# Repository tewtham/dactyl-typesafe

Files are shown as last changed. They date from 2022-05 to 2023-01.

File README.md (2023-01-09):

# Dactyl TypeSafe
A vertical split keyboard inspired by the [SafeType](https://www.amazon.com/SafeType-Keyboard-Black-Color-V902/dp/B0049PFYWQ) and [dactyl](https://github.com/adereth/dactyl-keyboard).
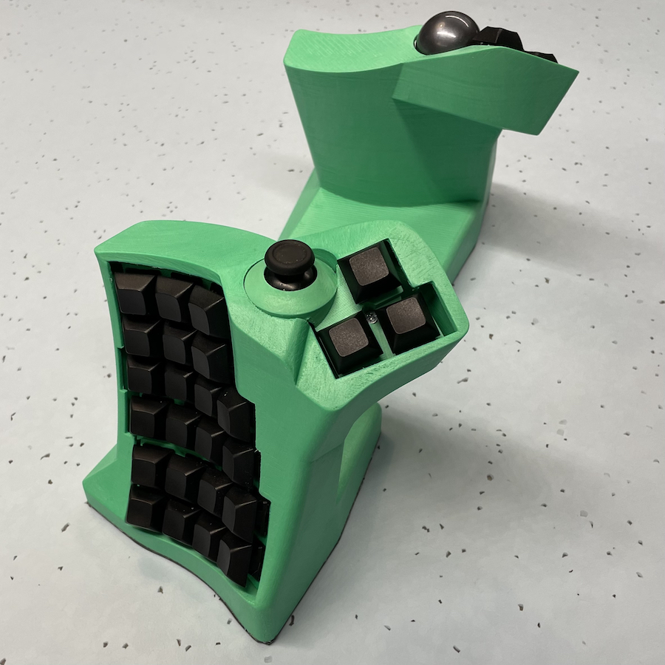
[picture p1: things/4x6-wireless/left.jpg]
left

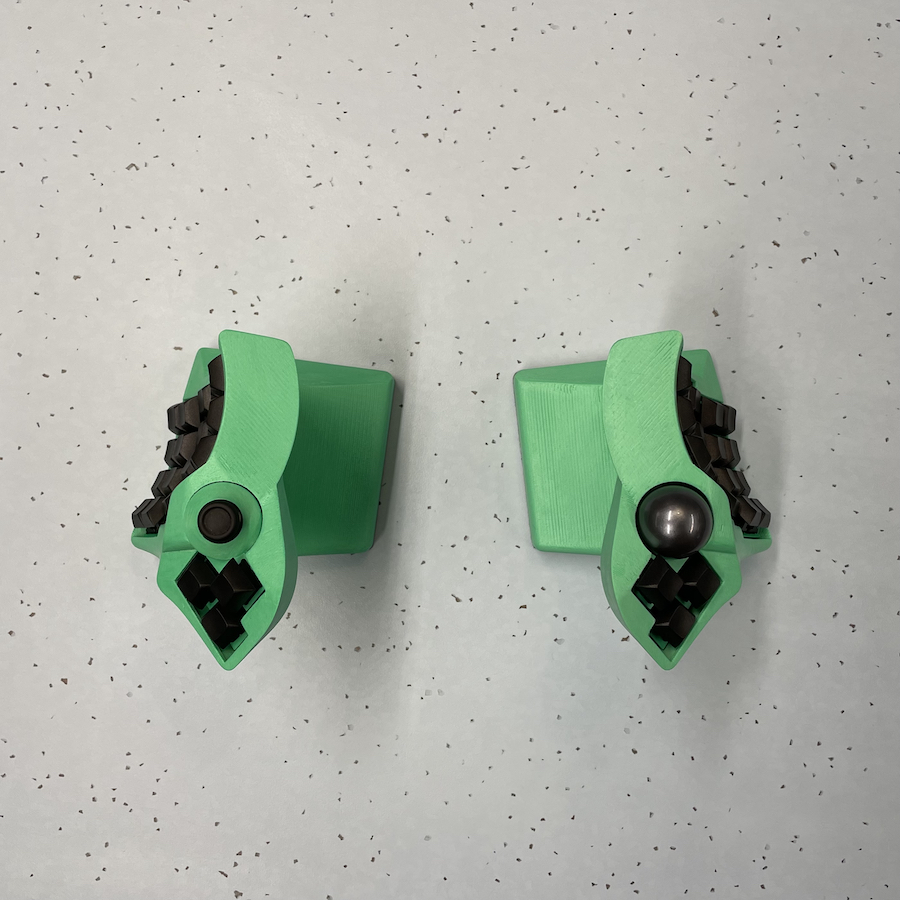
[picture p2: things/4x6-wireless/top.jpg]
both

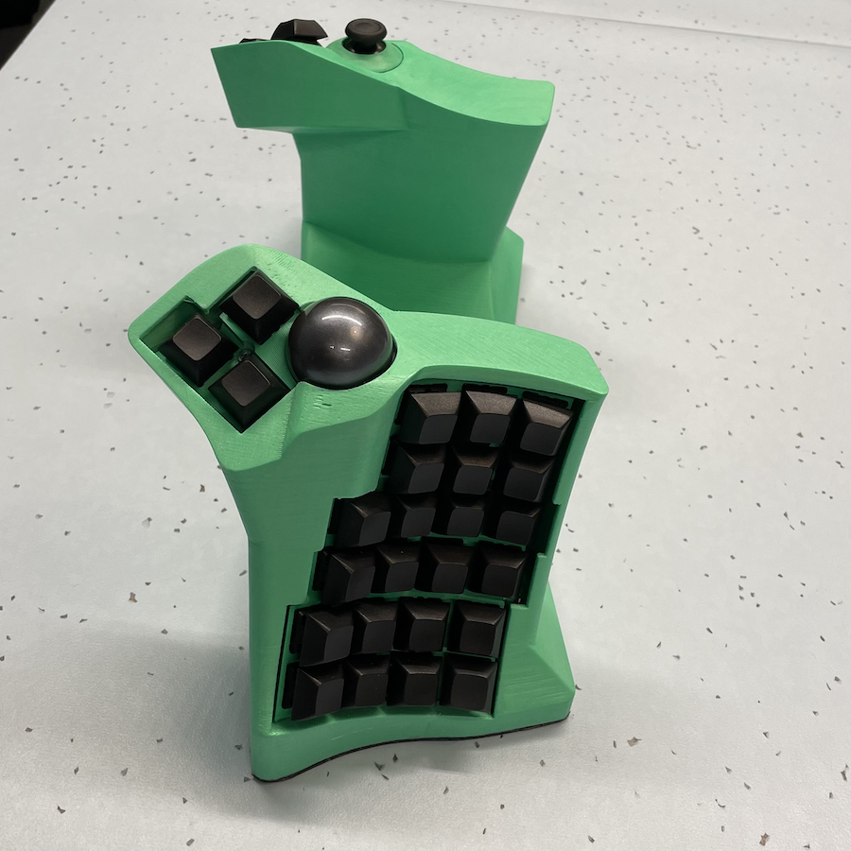
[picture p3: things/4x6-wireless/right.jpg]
right


## Parts list
1. [nylon 8mm ball transfer units](https://www.aliexpress.com/item/32839736943.html) * 3 for the trackball.
1. [non-slip mat](https://www.amazon.com/ROOS-Self-Stick-Anti-Skid-Furniture-Protectors/dp/B01K7JFXAA)
1. 34mm ball
    - Any 34mm ball will probably work, but I think it's best to use [a replacement trackball](https://www.aliexpress.com/item/4000351102541.html). You will get better response and precision.
1. [pmw3360 laser sensor board](https://www.tindie.com/products/jkicklighter/pmw3360-motion-sensor/)
1. 2 * [nice!nano](https://nicekeyboards.com/nice-nano/) boards.
1. a dualshock style joystick
    - I had pretty good luck cutting out the joysticks from a broken ds4 someone gave me, but I think you can buy these new also.
1. M3 [heat set inserts](https://www.aliexpress.com/item/2255800878462496.html) and countersunk bolts
1. M2 nuts/bolts for the laser sensor
1. [jst connectors](https://www.aliexpress.com/item/2255800221261384.html) for at least the thumb clusters (see [wiring](things/4x6-wireless/wiring.jpg))
1. A bunch of 95mm width metal plates (see [weights](things/4x6-wireless/weights.jpg))
1. Some batteries (I used some AA shaped ones so I can remove them)

## Some (light) build instructions
### wiring
1. There are a lot of guides for handwiring keyboards out there ([this one seems nice](https://www.crackedthecode.co/a-complete-guide-to-building-a-hand-wired-keyboard/#hand-wiring-your-keyboard)), so for the basics start with one of those.
    - Make sure to wire around [these spots](avoid_it.png). When it's assembled, there will be something there. 
    - I *highly* recommend using colored wire to keep track of everything [here](wiring.png) are the colors I use.
    - Since the thumb clusters are separated from everything by the case, I thought is was kind of nice to use [jst connectors](https://www.aliexpress.com/item/2255800221261384.html) (need the 4p ones) to connect them to the rest. This way it can be disassembled without clipping wires. Should use these for the joystick as well. I'll add some pictures of what that look like.
1. For the typesafe, besides wiring up the the colums/rows for each half to a n!n, we also need to hook up a laser sensor and joystick. Refer to my [drawing](wiring.png) for what that should look like.
### assembly
// TODO

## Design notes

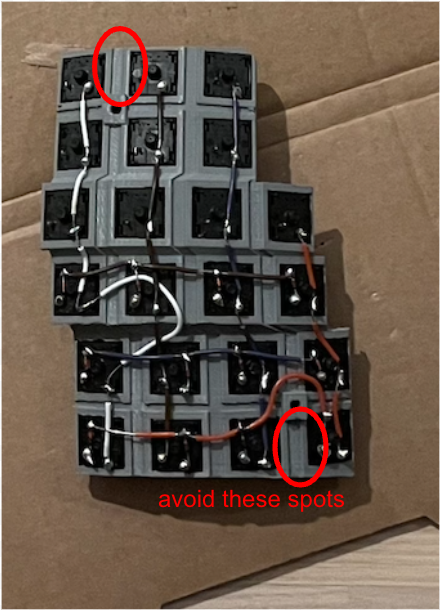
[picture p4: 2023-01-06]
avoid_it.png

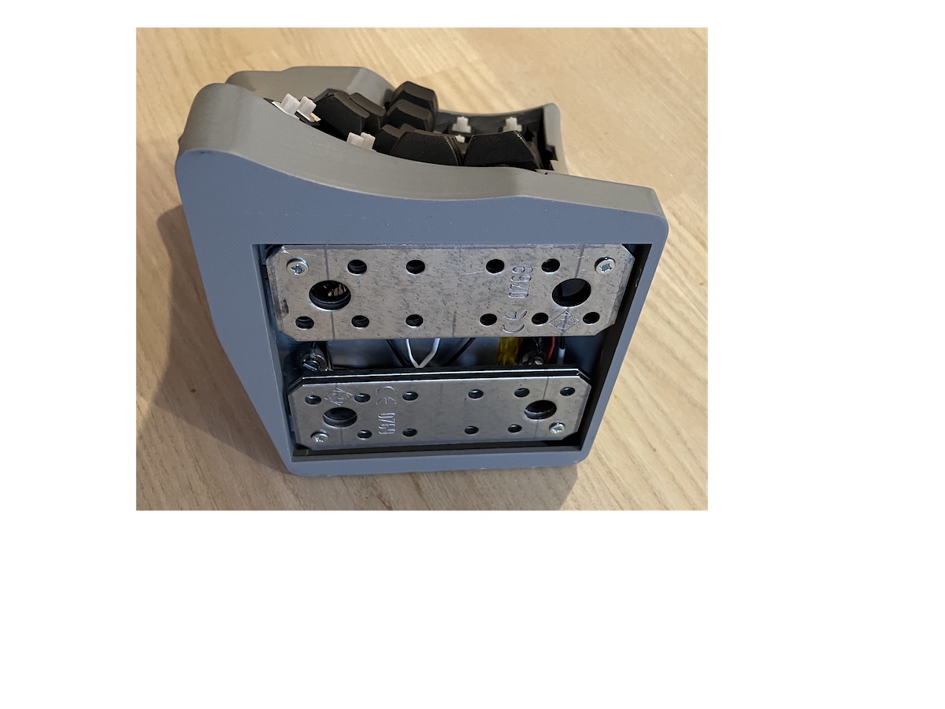
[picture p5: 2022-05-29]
things/4x6-wireless/weights.jpg

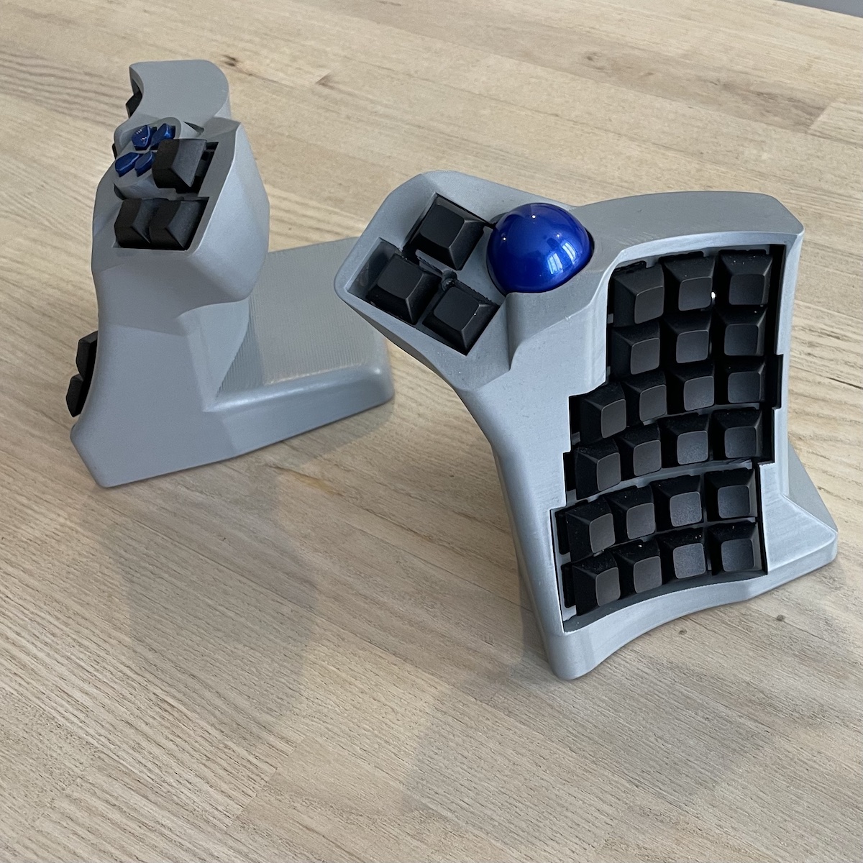
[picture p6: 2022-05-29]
things/4x6-wireless/right_angled.jpg

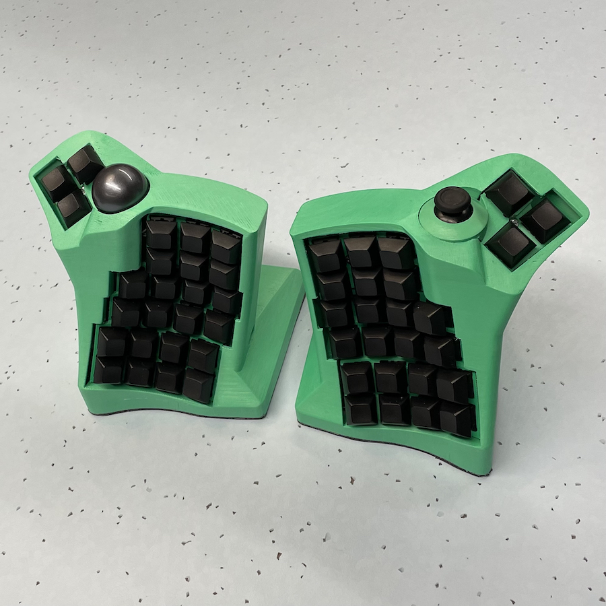
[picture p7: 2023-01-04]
things/4x6-wireless/both.jpg

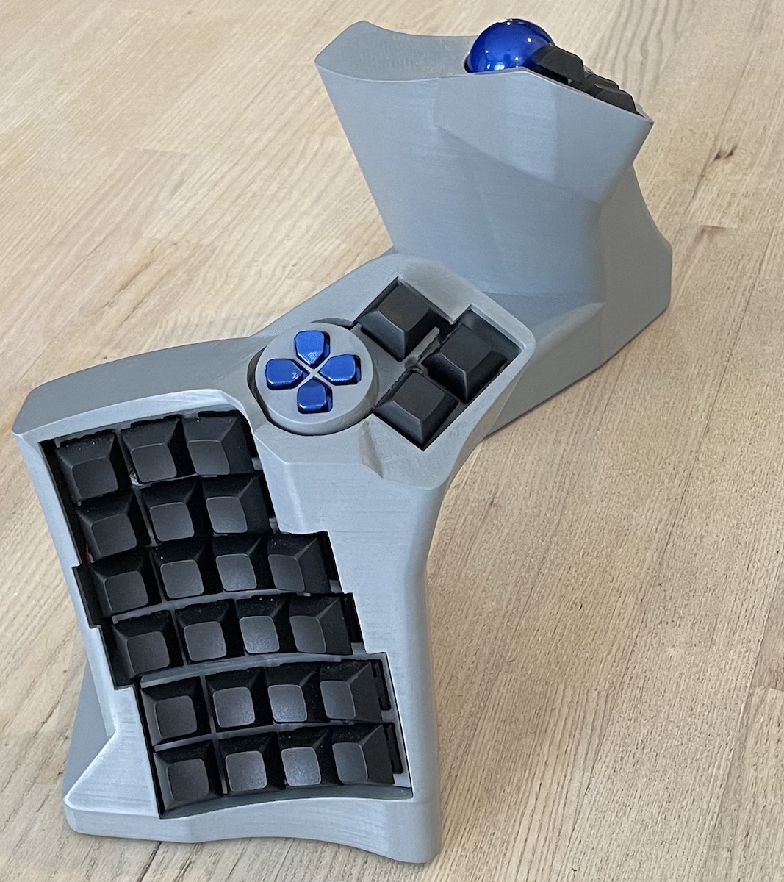
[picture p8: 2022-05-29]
things/4x6-wireless/left_angled.jpg

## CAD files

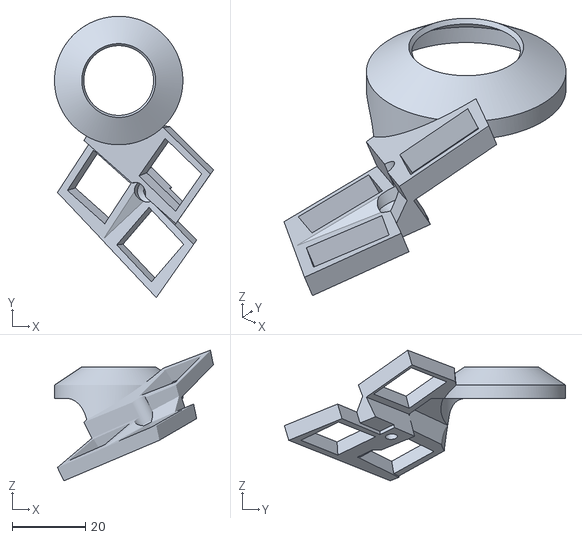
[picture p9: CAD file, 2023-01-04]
things/4x6-wireless/left-thumb-switches.stl
43.3 x 76.7 x 35.6

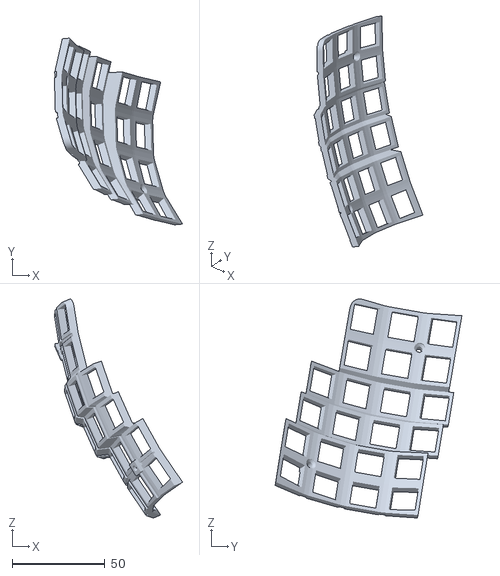
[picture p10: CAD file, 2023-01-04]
things/4x6-wireless/right-switches.stl
69.1 x 100.6 x 118.0

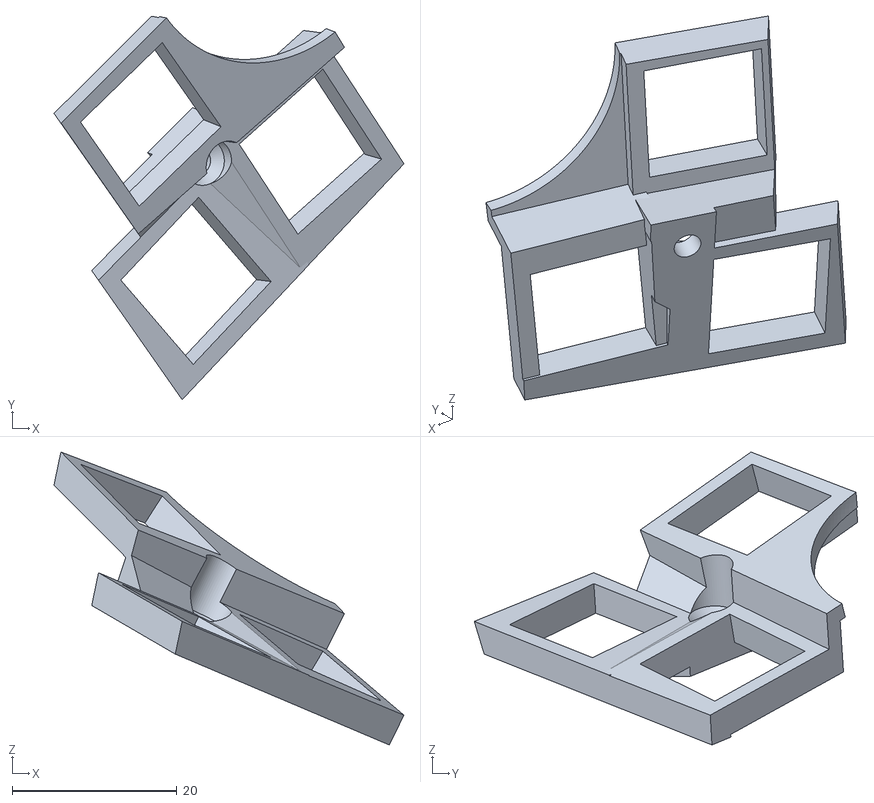
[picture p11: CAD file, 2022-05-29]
things/4x6-wireless/right-thumb-switches.stl
42.6 x 46.6 x 35.6

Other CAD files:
things/4x6-wireless/left-switches.stl

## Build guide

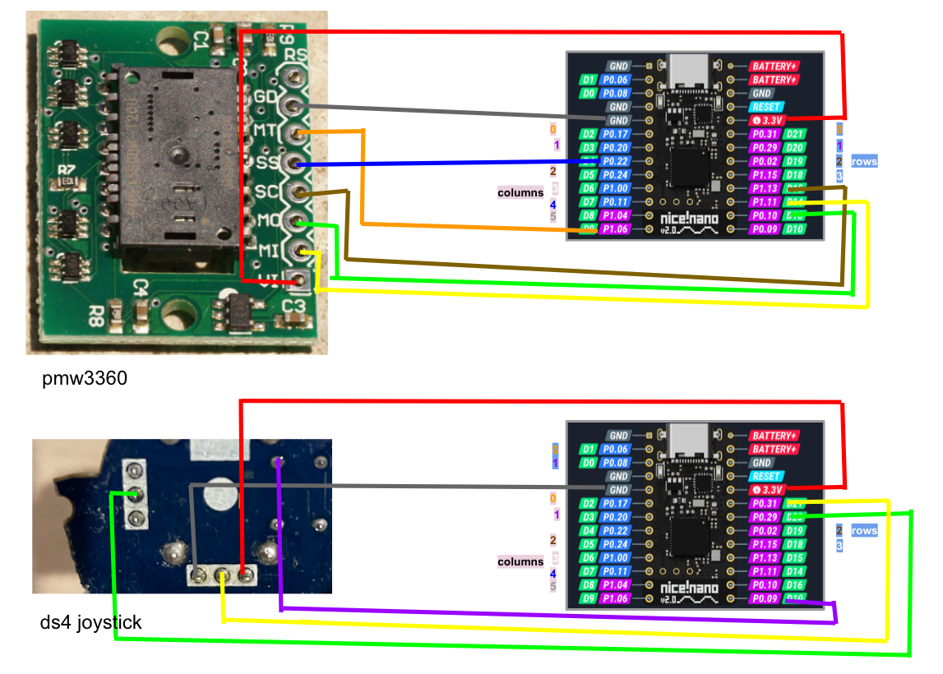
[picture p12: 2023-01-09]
wiring.png

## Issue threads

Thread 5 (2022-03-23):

Design files

sickerin, 2022-03-23:
Hi @tewtham, what did you use to design this? Would you be able to share the design files? From my understanding, STL files are usually hard to make modification rights?

tewtham, 2022-05-29:
Hey! sorry for the late reply. I used [fusion360](https://www.autodesk.com/products/fusion-360/personal) to do the design. My design files are quite messy, so I wasn't really planning on releasing them. You would probably find it pretty difficult to make modifications even with those 😅 .

I do have a fork of the [dactyl keyboard](https://github.com/tewtham/dactyl-keyboard) which only generates the key switch openings. This is what I've been basing all my designs on.

Closed 2022-05-29.

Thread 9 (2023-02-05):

GuliKit Hall Joystick

suwagawaki, 2023-02-05:
Thanks for sharing the design! Will a [GuliKit hall effect joycon joystick](https://www.gulikit.com/productinfo/945307.html) work as an alternative to the dualshock analog stick?

tewtham, 2023-02-05:
Yes, I think it can work, but you would need to fabricate a small riser since it is a bit shorter than the dualshock. My only concern would be that the opening is slightly wider (2-3mm) and more curved than the one on the switch. Could try just printing out the [left thumb switch](https://github.com/tewtham/dactyl-typesafe/blob/main/things/4x6-wireless/left-thumb-switches.stl) piece to see how well it fits. I might try it myself if I come across a broken switch controller!

Closed 2023-02-06.

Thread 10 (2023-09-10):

Version with more keys on the side

burivuh26, 2023-09-10:
I saw at Reddit photos of first version of this keyboard with 28 keys at the side and 3-5 keys at the tumb. I didn't faint Stl-files for bigger versions of this keyboard at the GitHub.can you please add them?
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

tewtham, 2023-09-11:
Actually, these should already be available in an older commit [here](https://github.com/tewtham/dactyl-typesafe/tree/19f1c7c73a30299ffdcf735b0b7b016b3c7a2650/things/5x6). You can also find it from this tag https://github.com/tewtham/dactyl-typesafe/releases/tag/1.0.0

Closed 2023-09-11.

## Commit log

2020-10-02 Checking in code and design files
    [left-bottom.stl, right-bottom.stl]
2020-11-17 add some assembly notes
2020-12-05 removing some unnecessary pieces from the bottoms
    [left-bottom.stl, right-bottom.stl]
2020-12-27 WIP 4x6 redesign
    [left-back.stl, left-bottom.stl, right-back.stl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]
2021-04-09 fixing the openings for the trackball bearings
2021-09-26 Wireless design
    [left-switches.stl, left-thumb-switches.stl, right-switches.stl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]
2021-09-27 Smoothing out some of the corners
    [left-switches.stl, right-switches.stl]
2021-11-05 fixing a few problems
    [left-switches.stl, left-thumb-switches.stl, right-switches.stl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]
2021-11-05 small fix to left thumb cluster
    [left-thumb-switches.stl]
2022-05-29 Updating the docs and removing all the old stuff
    [left-bottom.stl, right-bottom.stl]
2022-05-29 Fix tact switch link
2023-01-04 Joystick (#6)
    * Updating stls for pmw3360 and a joystick
    [left-switches.stl, left-thumb-switches.stl, right-switches.stl]
2023-01-06 Adding a bit of documentation about wiring (#7)
